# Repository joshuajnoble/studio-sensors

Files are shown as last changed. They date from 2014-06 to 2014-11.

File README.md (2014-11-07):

===============================================
frog studio sensor
===============================================

Let's keep it simple at first: there's a server and you can pull info from it. Here's what some of that info looks like:

```
[{"id":134,"sensor_id":1,"time":"2014-03-24T23:48:55.442Z","light":1,"sound":114,"movement":1,"temp":18,"humidity":147,"brightness":0},
{"id":135,"sensor_id":1,"time":"2014-03-24T23:49:20.120Z","light":1347,"sound":562,"movement":0,"temp":34,"humidity":3,"brightness":0}]
```

Whoa. That's JSON!

The frog studio sensors log all their data up there to my server every 15 seconds. 

Ok, so we have a few things in there:

* sensor_id: what sensor is it?
* studio: what studio is it in?
* zone: what part of the studio is it in?
* time: that's a timestamp (this is in GMT)
* sound: scale from 0-30 (afaict)
* movement: has anything moved in that zone in the last 30 seconds?
* humidity: what's the relative humidity (percent)
* temperature: Celsius
* light: light frequency in values from 480-600 (afaict)
* brightness: not being used right now

The raspberry pi just logs its data using a URL like:

`http://OUR_URL:3000/?i=1&l=343&s=232&t=22&h=33&m=0&&studio=sea&zone=1`

You can make fake (test) posts all you want.

===============================================
VISUALIZATION
===============================================

Where's the visualization? Good question. Have you made one yet? No? Well there's your answer. This is meant to look different to each studio. There are a few basic pattern goes like so:

`/view?params`

Let's look at some more stuff in here. You're *probably* going to want to just use the following:

`URL:3000/view?studio=SEA&begindate=24032014&begintime=1600&enddate=24032014&endtime=1700`

That gives you all the data from Seattle from 24032014:1600 to 24032014:1700 thats DDMMYY:24HR

There is more though, be warned though, these datasets can get massive and pulling them all is *slow*

All studios by date:

`URL:3000/view?begindate=24032014&begintime=1600&enddate=24032014&endtime=1700`

The last reading by zone

`URL:3000/view?studio=SEA&zone=1&last=1`

All readings by zone

`URL:3000/view?studio=SEA&zone=1`

All readings by sensorid (good for debugging)

`URL:3000/view?id=1`

Timeboxed view of a particular zone:

`URL:3000/?i=1&l=343&s=232&t=22&h=33&m=0&&studio=sea&zone=1`

All readings from the last hour

`URL:3000/view?recent=1&zone=1&studio=SEA`

The last reading of a studio

`URL:3000/view?now=1&studio=SEA`

Want more? It's very easy to add. Just take a look at studio-sensors/server.js for tips on how to make it better.

===============================================
DEVICE INFO
===============================================

The device is a Raspberry pi with some sensors on it. The first thing the device does is start up, report its IP, studio (within frog), location (zone), and then get a sensor id that will follow it as long as it (it, in this case being the SD card) exists.

This is accessed like so:

`$URL/get_id?studio=SEA&zone=1&ip=172.189.128.112`

When the machine is kicked off the network and hops back on that it updates its IP. This is done like so:

`$URL/update_id?id=1&ip=172.189.128.112`

The id you see there is the same ID that is retrieved when the machine is first started up. 

Why is this "id => IP" mapping important? Well, so that you can always SSH into your device and see what's up with it, if it crashed, if the DHT22 burnt out, etc. That's what makes it worthwhile to have everything on the RPI.

To configure the device to run the studio sensor program you need to do a few different things first.

1) Install the drivers for the Edimax EW-7811Un USB WiFi chip

http://www.andreagrandi.it/2014/09/02/how-to-configure-edimax-ew-7811un-wifi-dongle-on-raspbian/

2) Install pigpio

http://abyz.co.uk/rpi/pigpio/

3) Install git

sudo apt-get install git

4) Install Adafruit DHT22 driver

https://github.com/adafruit/Adafruit_Python_DHT

===============================================
SERVER INFO
===============================================

I have my server set up to use upstart to start up our node application, it's logging to :"/etc/init/studioapi.conf" at the moment so you can see what's going on with it.

I'm using ec2 ubuntu.

To get things set up I just did the following:

`sudo apt-get install postgres node`

then 

`sudo vim /etc/postgresql/9.3/main/postgresql.conf`

uncomment the line that says: `#listen_addresses = 'localhost' `
then
`sudo vim /etc/postgresql/9.3/main/pg_hba.conf`

then

`sudo service postgresql start`

then

```
sudo -i -u postgres
ubuntu@ip-172-31-30-171:~$ sudo -i -u postgres
postgres@ip-172-31-30-171:~$ psql
psql (9.3.5)
Type "help" for help.

ALTER USER postgres WITH PASSWORD '$password';
```

Create a job:

`sudo vim /etc/init/studioapi.conf`

then add:

```
description "node.js server"
author     "josh"

# used to be: start on startup
# until we found some mounts weren't ready yet while booting:
start on started mountall
stop on shutdown

# Automatically Respawn:
respawn
respawn limit 99 5

script
    # Not sure why $HOME is needed, but we found that it is:
    export HOME="/root"

    exec /usr/bin/node /home/joshuajnoble/studio-sensors/server.js >> /var/log/node.log 2>&1
end script

post-start script
   # Optionally put a script here that will notifiy you node has (re)started
   # /root/bin/hoptoad.sh "node.js has started!"
end script
```

===============================================
DB INFO
===============================================

Creating the DB is pretty simple:
```
create database sensordata;

create table sensors ( studio varchar(3), zone varchar(10), id integer, constraint uid unique(id), ip varchar(16) );

ALTER TABLE sensors ADD COLUMN key varchar(30);

ALTER TABLE sensors ADD CONSTRAINT uniquekey UNIQUE (key);

create table readings ( id serial, sensor id int not null, time timestamp with time zone not null, light int not null, sound int not null, movement int not null, temp int not null, humidity int not null, brightness int not null, zone varchar(30) not null, studio varchar(30) not null);
```

===============================================
Troubleshooting
===============================================

Can't get the Pi online?

Try making a little entry in crontab to make the RaspberryPi ping your router every minute. This will ensure that your wifi connection will stay alive. To edit crontab just type (from pi user, you don’t need to be root):

`crontab -e`

and insert this line at the end:

`*/1 * * * * ping -c 1 192.168.0.1`

where 192.168.0.1 is the IP of your router. I don't know what your studios router address will be, so you'll have to figure that out.

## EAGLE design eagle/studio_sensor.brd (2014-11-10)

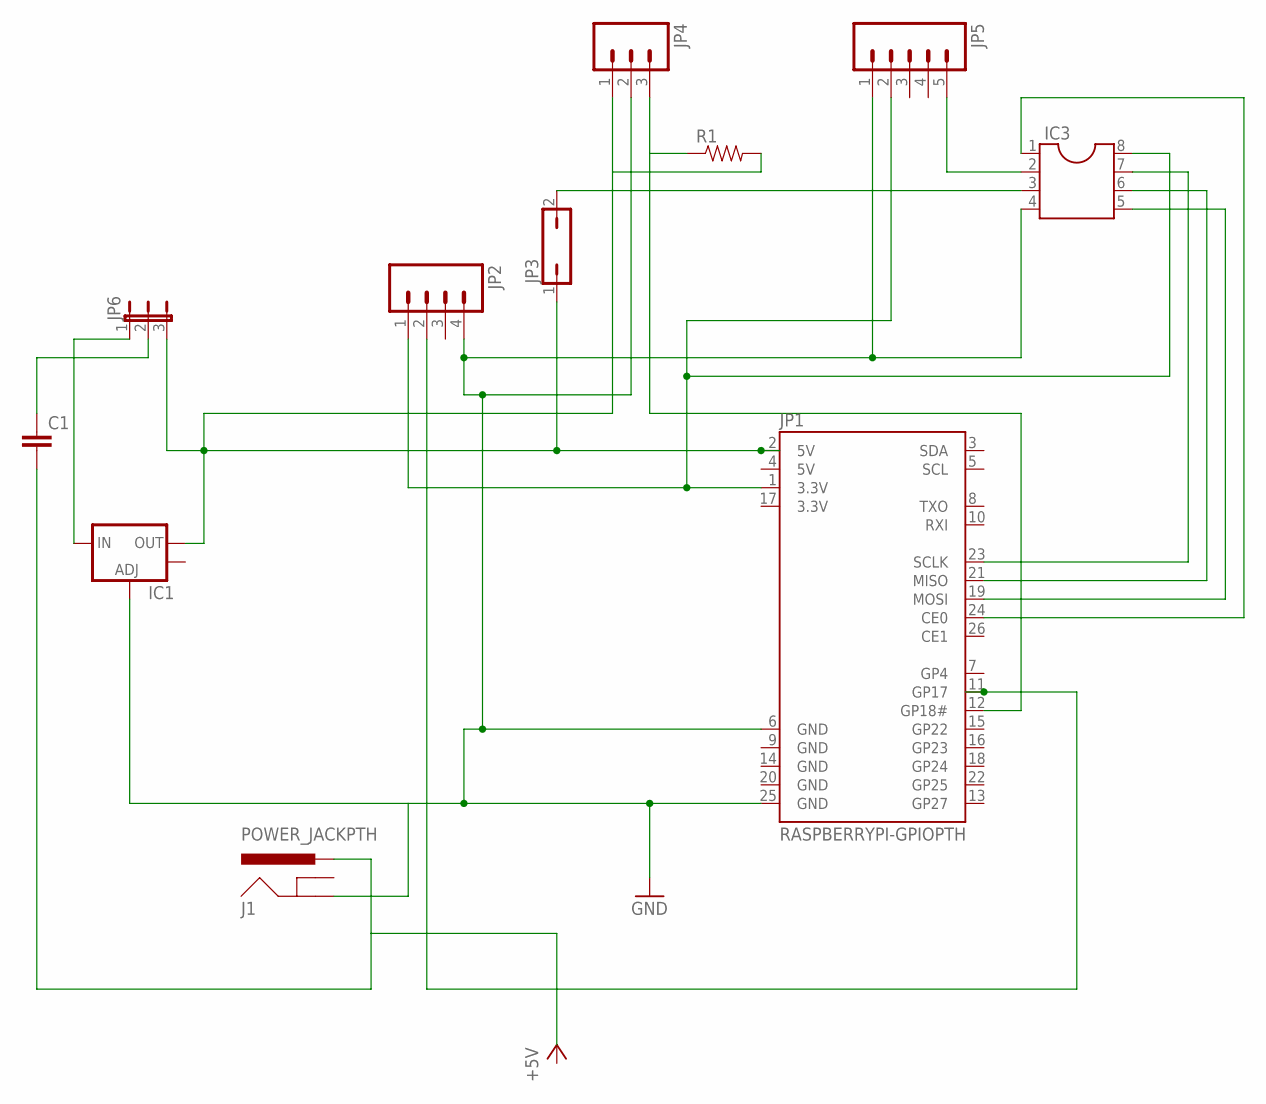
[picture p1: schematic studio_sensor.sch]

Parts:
C1: CAP0603-CAP; 0603-CAP
IC1: V_REG_LM1117SOT223; SOT223
IC3: DIL8S; SOCKET-08
J1: POWER_JACKPTH; POWER_JACK_PTH
JP1: RASPBERRYPI-GPIOPTH; 2X13-SHROUDED
JP2: M04PTH; 1X04
JP3: JP1Q; JP1
JP4: M03PTH; 1X03
JP5: M05PTH; 1X05
JP6: JP2E; JP2
R1: 4.7OHM1/10W5%(0603); 0603

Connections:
3.3V: JP1.17 (3.3V)
5V: JP1.4 (5V)
GND: IC1.1 (ADJ), IC3.4, J1.GND, JP1.6 (GND), JP1.9 (GND), JP1.14 (GND), JP1.20 (GND), JP1.25 (GND), JP2.4, JP4.2, JP5.1
unnamed: IC1.2 (OUT), JP1.2 (5V), JP3.1, JP4.1, JP6.3, R1.2
unnamed: IC3.8, JP1.1 (3.3V), JP2.1, JP5.2
unnamed: IC3.3, JP3.2
unnamed: IC3.7, JP1.23 (SCLK)
unnamed: IC3.6, JP1.21 (MISO)
unnamed: IC3.5, JP1.19 (MOSI)
unnamed: IC3.1, JP1.24 (CE0)
unnamed: IC3.2, JP5.5
unnamed: IC1.3 (IN), JP6.1
unnamed: JP1.11 (GP17), JP2.2
unnamed: C1.2, J1.PWR
unnamed: C1.1, JP6.2
unnamed: JP1.12 (GP18#), JP4.3, R1.1

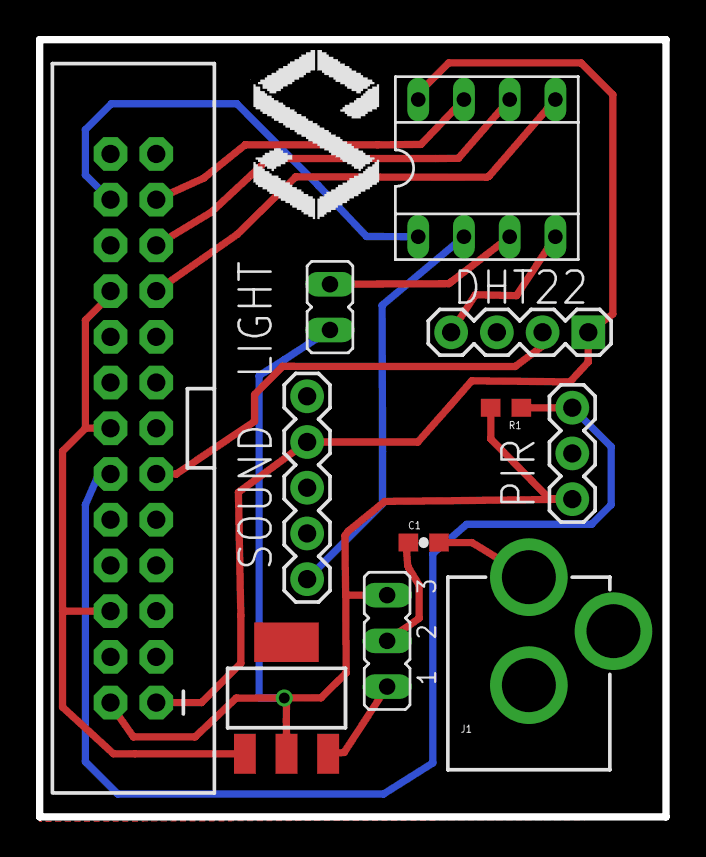
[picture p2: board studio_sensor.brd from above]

Board: 2 copper layers, 34.8 x 43.2 mm, 11 parts (0 on the bottom side), 14 nets.

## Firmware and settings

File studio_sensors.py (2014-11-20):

from __future__ import division
import struct
import socket
import fcntl
import getopt
import spidev
import time
import sys
from time import sleep
import pigpio
import urllib2
import httplib
import Adafruit_DHT
import datetime
import os
import contextlib
import subprocess
from subprocess import call

zone = ""
studio = ""

TSL235_pin = 7
DHT22_pin = 17
sensor_id = -1

IP = "54.191.189.58"
PORT = "3000"

def bitstring(n):
    s = bin(n)[2:]
    return '0'*(8-len(s)) + s

def readADC(adc_channel=0, spi_channel=0):
	conn = spidev.SpiDev(0, spi_channel)
	conn.max_speed_hz = 500000 # 1.2 MHz
	conn.mode = 0
	cmd = 192
	if adc_channel != 0:
		cmd += 32
	reply_bytes = conn.xfer2([cmd, 0])
	reply_bitstring = ''.join(bitstring(n) for n in reply_bytes)
	reply = reply_bitstring[5:15]
	conn.close()
	return int(reply, 2)

def get_ip_address(ifname):
	s = socket.socket(socket.AF_INET, socket.SOCK_DGRAM)
	return socket.inet_ntoa( fcntl.ioctl( s.fileno(), 0x8915, struct.pack('256s', ifname[:15]) )[20:24] )

def downUp():
	subprocess.Popen(["ifdown", "wlan0"],close_fds=True)
	sleep(10)
	subprocess.Popen(["ifup", "wlan0"],close_fds=True)
	sleep(20)


def rebootWlan0():
	downUp()
	hasIP = False
	while(hasIP == False):
		try:
			ip = get_ip_address("wlan0")
			hasIP = True
		except IOError:
			downUp()


	request = urllib2.Request('http://'+IP+':'+PORT+'/update_ip?id='+sensor_id+'&ip=' + ip)
	# recursively calls itself, could be bad
	try:
		response = urllib2.urlopen(request)
	except urllib2.HTTPError, e:
		#response.close()
		print(str(datetime.datetime.now()) + 'HTTPError = ' + str(e.code) )
		rebootWlan0()
	except urllib2.URLError, e:
		#response.close()
		rebootWlan0()
		print(str(datetime.datetime.now()) + 'URLError = ' + str(e.reason))
	except Exception:
		#response.close()
		import traceback
		print(str(datetime.datetime.now()) + 'generic exception: ' + traceback.format_exc())
		rebootWlan0()
		print(str(datetime.datetime.now()) +  " http error " )


def getHwAddr(ifname):
	s = socket.socket(socket.AF_INET, socket.SOCK_DGRAM)
	info = fcntl.ioctl(s.fileno(), 0x8927,  struct.pack('256s', ifname[:15]))
	return ''.join(['%02x' % ord(char) for char in info[18:24]])



# now begin the actual loop
####################################################################################################

if __name__ == "__main__":

	# Read command line args
	#myopts, args = getopt.getopt(sys.argv[1:],"s:z:")
 
	###############################
	# o == option
	# a == argument passed to the o
	###############################
	#for o, a in myopts:
	#	if o == '-s':
	#		studio=a
	#	elif o == '-z':
	#		zone=a
	#	else:
	#		print(str(datetime.datetime.now()) + "Usage: %s -s studio -z zone" % sys.argv[0])


	# FIRST
	# do we know our zone and studio?
	
	print( str(datetime.datetime.now()) + "start ") 
	has_studio_zone = False

	if os.path.isfile('studio_sensor_studio_zone') == False:
		print(str(datetime.datetime.now()) + " no studio + zone, getting one from server ")
		mac = getHwAddr("wlan0")
		print(str(datetime.datetime.now()) + " my mac is " + str(mac))
		while has_studio_zone == False:
			print(str(datetime.datetime.now()) +  " going to mac request from " + IP + ":" + PORT)
			request = urllib2.Request("http://"+str(IP)+":"+str(PORT)+"/get_studio_zone?mac="+str(mac))
			try:
				response = urllib2.urlopen(request)
				studio_zone = response.read()
				print(str(datetime.datetime.now()) + " got studio + zone " + str(studio_zone).split(':')[0] + " " + str(studio_zone).split(':')[1])
				f = open('studio_sensor_studio_zone', 'w')
				f.write(str(studio_zone))
				f.close()
				response.close()
				has_studio_zone = True
			except IndexError, e:
				print( str(datetime.datetime.now()) + " service didn't find this MAC address, add for this device and restart ")
				sys.exit()
			except urllib2.HTTPError, e:
				if(e.code == 409):
					print(str(datetime.datetime.now()) + ' DB error configure MAC ' + str(e.code))
					sys.exit()

 
				print(str(datetime.datetime.now()) + 'HTTPError = ' + str(e.code))
				#print(str(datetime.datetime.now()) + 'HTTPError = ' + str(e.code))
				downUp()
			except urllib2.URLError, e:
				downUp()
				print(str(datetime.datetime.now()) + 'URLError = ' + str(e.reason))
			except httplib.HTTPException, e:
				if(e.code == 409):
					print(str(datetime.datetime.now()) + ' DB error configure MAC ' + str(e.code))
					sys.exit()
				downUp()
				print(str(datetime.datetime.now()) + 'HTTPException')
			except Exception:
				import traceback
				print(str(datetime.datetime.now()) + 'generic exception: ' + traceback.format_exc())
			sleep(10)

	# we know our zone and studio, lets load it in

	if os.path.isfile('studio_sensor_studio_zone') == True:
		f = open('studio_sensor_studio_zone', 'r')
		studio_zone = f.read()
		studio = str(studio_zone).split(":")[0]
		zone = str(studio_zone).split(":")[1]
		f.close()    

	print (studio + " " + zone)

	pir_pin = 18
	pi = pigpio.pi()
	pi.set_mode(pir_pin, pigpio.INPUT)         # activate input

	sensor = Adafruit_DHT.DHT22

	pir_triggered = False
	has_id = False

	# if you have an ID file then you don't need to do this

	if os.path.isfile('studio_sensor_id') == False:
		print(str(datetime.datetime.now()) + " no ID, getting one from server ")
		ip = get_ip_address("wlan0")
		print(str(datetime.datetime.now()) + " my IP is " + str(ip))
		while has_id == False:
			print(str(datetime.datetime.now()) +  " going to request from " + IP + ":" + PORT)
			request = urllib2.Request("http://"+str(IP)+":"+str(PORT)+"/get_id?studio="+str(studio)+"&zone="+str(zone)+"&ip="+str(ip))
			#request = urllib2.Request("http://54.191.189.58:3000/get_id?studio=SEA&zone=1&ip=127.0.0.1")

			try:
				response = urllib2.urlopen(request)
				sensor_id = response.read()
				print(str(datetime.datetime.now()) + " got ID " + str(sensor_id))
				f = open('studio_sensor_id', 'w')
				f.write(str(sensor_id))
				f.close()
				response.close()
				has_id = True
			except urllib2.HTTPError, e:
				 print(str(datetime.datetime.now()) + 'HTTPError = ' + str(e.code))
				 downUp();
			except urllib2.URLError, e:
				 downUp();
				 print(str(datetime.datetime.now()) + 'URLError = ' + str(e.reason))
			except httplib.HTTPException, e:
				 downUp();
				 print(str(datetime.datetime.now()) + 'HTTPException')
			except Exception:
				 import traceback
				 print(str(datetime.datetime.now()) + 'generic exception: ' + traceback.format_exc())
				
			sleep(10)

	if os.path.isfile('studio_sensor_id') == True:
		f = open('studio_sensor_id', 'r')
		sensor_id = f.read()        
		f.close()    

	sound_values = [0] * 150
	sound_index = 0
	last_send = time.time()
	last_sound_sample = last_send

	while 1:
		sleep(0.05)
		if pi.read(pir_pin) == False:
			pir_triggered = True
		else:
			pir_triggered = False

		if( time.time() - last_sound_sample) > 5:
			sound_values[sound_index] = readADC()
			sound_index += 1
			last_sound_sample = time.time()

		# every 5 minutes?
		if (time.time() - last_send) > 300:
			print(str(datetime.datetime.now()) +  " sending ")
			send = "i=" + str(sensor_id) + "&studio="+ studio+ "&zone="+ zone
			if pir_triggered:
				send += "&m=1"
			else:
				send += "&m=0"
			light_value = readADC(1) #light is now just on MCP3002, tsl235 can stuff it
			send += "&l=" + str(light_value)
			
			sound_sum = 0
			for val in range(sound_index):
				sound_sum += abs( 512 - sound_values[val] )

			send += "&s=" + str(sound_sum / sound_index)
			# all done with sounds until next send
			sound_index = 0
			humidity, temperature = Adafruit_DHT.read_retry(sensor, DHT22_pin)
			print(str(datetime.datetime.now()) +  str(temperature) + " " + str(humidity))
			if temperature != None:
				send += "&t=" + str(int(temperature))
			else:
				send += "&t=0"

			if humidity != None:
				send += "&h=" + str(int(humidity))
			else:
				send += "&h=0"

			print(str(datetime.datetime.now()) +  send )

			# we're going to want this to allow us to pull this out of the
			# config file so it can be set from the desktop I'd think
			request = urllib2.Request('http://'+IP+':'+PORT+'/?'+send)
			try: 
				response = urllib2.urlopen(request)
				response.close()
			except urllib2.HTTPError, e:
				#response.close()
				print(str(datetime.datetime.now()) + " HTTP ERROR = " + str(e.code))
				if( e.code == 409 ):
					print(str(datetime.datetime.now()) + " We're getting a 409 which means a misconfigured request and resulting DB error ")
				else:
					rebootWlan0()
			except urllib2.URLError, e:
				#response.close()
				rebootWlan0()
				print(str(datetime.datetime.now()) + 'URLError = ' + str(e.reason))
			except Exception:
				#response.close()
				import traceback
				print(str(datetime.datetime.now()) + 'generic exception: ' + traceback.format_exc())
				rebootWlan0()
				print(str(datetime.datetime.now()) +  " http error " )

			last_send = time.time()
# end

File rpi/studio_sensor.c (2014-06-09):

#include <stdio.h>
#include <stdlib.h>
#include <unistd.h>
#include <errno.h>
#include <string.h>
#include <netdb.h>
#include <sys/types.h>
#include <netinet/in.h>
#include <sys/socket.h>

#include <arpa/inet.h>

#define PORT "3000" // the port client will be connecting to 

#define MAXDATASIZE 100 // max number of bytes we can get at once 
spiDevice *spiDevice;

struct atmosphereData {
  char temp[2];
  char humidity[2];
}

// get sockaddr, IPv4 or IPv6:
void *get_in_addr(struct sockaddr *sa)
{
    if (sa->sa_family == AF_INET) {
        return &(((struct sockaddr_in*)sa)->sin_addr);
    }

    return &(((struct sockaddr_in6*)sa)->sin6_addr);
}

int connectAndSend(int argc, char *argv[])
{
    int sockfd, numbytes;  
    char buf[MAXDATASIZE];
    struct addrinfo hints, *servinfo, *p;
    int rv;
    char s[INET6_ADDRSTRLEN];

    memset(&hints, 0, sizeof hints);
    hints.ai_family = AF_UNSPEC;
    hints.ai_socktype = SOCK_STREAM;

    if ((rv = getaddrinfo(hostname, PORT, &hints, &servinfo)) != 0) {
        fprintf(stderr, "getaddrinfo: %s\n", gai_strerror(rv));
        return 1;
    }

    // loop through all the results and connect to the first we can
    for(p = servinfo; p != NULL; p = p->ai_next) {
        if ((sockfd = socket(p->ai_family, p->ai_socktype, p->ai_protocol)) == -1) {
            perror("client: socket");
            continue;
        }

        if (connect(sockfd, p->ai_addr, p->ai_addrlen) == -1) {
            close(sockfd);
            perror("client: connect");
            continue;
        }

        break;
    }

    if (p == NULL) {
        fprintf(stderr, "client: failed to connect\n");
        return 2;
    }

    inet_ntop(p->ai_family, get_in_addr((struct sockaddr *)p->ai_addr), s, sizeof s);
    printf("client: connecting to %s\n", s);

    freeaddrinfo(servinfo); // all done with this structure

    if ((numbytes = recv(sockfd, buf, MAXDATASIZE-1, 0)) == -1) {
        perror("recv");
        exit(1);
    }

    buf[numbytes] = '\0';

    printf("client: received '%s'\n",buf);

    close(sockfd);
}

int readVolume( int pin )
{
  spiWriteRead( )
}


int readDHT(int pin, atmosphereData* aData) {
  int counter = 0;
  int laststate = HIGH;
  int j=0;

  // Set GPIO pin to output
  bcm2835_gpio_fsel(pin, BCM2835_GPIO_FSEL_OUTP);

  bcm2835_gpio_write(pin, HIGH);
  usleep(500000);  // 500 ms
  bcm2835_gpio_write(pin, LOW);
  usleep(20000);

  bcm2835_gpio_fsel(pin, BCM2835_GPIO_FSEL_INPT);

  data[0] = data[1] = data[2] = data[3] = data[4] = 0;

  // wait for pin to drop?
  while (bcm2835_gpio_lev(pin) == 1) {
    usleep(1);
  }

  // read data!
  for (int i=0; i< MAXTIMINGS; i++) {
    counter = 0;
    while ( bcm2835_gpio_lev(pin) == laststate) {
      	counter++;
      	//nanosleep(1);		// overclocking might change this?
        if (counter == 1000) {
	         break;
         }
    }
    laststate = bcm2835_gpio_lev(pin);
    if (counter == 1000) break;
    bits[bitidx++] = counter;

    if ((i>3) && (i%2 == 0)) {
      // shove each bit into the storage bytes
      data[j/8] <<= 1;
      if (counter > 200)
        data[j/8] |= 1;
      j++;
    }
  }


#ifdef DEBUG
  for (int i=3; i<bitidx; i+=2) {
    printf("bit %d: %d\n", i-3, bits[i]);
    printf("bit %d: %d (%d)\n", i-2, bits[i+1], bits[i+1] > 200);
  }
#endif

  printf("Data (%d): 0x%x 0x%x 0x%x 0x%x 0x%x\n", j, data[0], data[1], data[2], data[3], data[4]);

  if ((j >= 39) && (data[4] == ((data[0] + data[1] + data[2] + data[3]) & 0xFF)) ) 
  {
     // yay!
 
  	float f, h;
  	h = data[0] * 256 + data[1];
  	h /= 10;

  	f = (data[2] & 0x7F)* 256 + data[3];
    f /= 10.0;
    if (data[2] & 0x80)  f *= -1;
    //printf("Temp =  %.1f *C, Hum = %.1f \%\n", f, h);
    itoa(f, aData->temp);
    itoa(h, aData->humidity);
    return 1;
  }

  return 0;
}

void main()
{
  spiDevice = malloc(sizeof(spiDevice));
  spiDevice->mode = SPI_MODE_0;
  spiDevice->bitsPerWord = 8;
  spiDevice->speed = 1000000;
  spiDevice->spifd = -1;

  char adc08636 = "/dev/spidev0.0";

  if(spiOpen(spiDevice, adc08636, sizeof(adc08636)) < 0) {
    perror(" can't open spidev0.0");
  }

  atmosphereData dhtData;
  unsigned char dataDump[255];
  unsigned char spiData[2];
  int soundValue;

  while()
  {

    /*

      keep track of time,
      check sound, check movement
      if it's been long enough, throw it up to the sensor

     */

    readDHT( dhtPin, &dhtData );
    spiWriteRead( &spiDevice, )
    // we dont really care what we're sending b/c we're only reading
    soundValue = connectAndSend( &spiData[0], 2 );
    

  }


}

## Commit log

2014-03-15 adding arduino files
2014-03-18 adding proper URL, adjusting interrupt
    [soldering.fzz]
2014-03-25 updating server and arduino
2014-03-26 cleaning up arduino app
2014-04-17 re-adding studio sensors
2014-05-01 updating server, last ditch try w/the watchdog timer
2014-06-13 updating dht sensor reading
2014-07-23 adding studio sensors py
2014-08-08 adding schematics
    [studio_sensor.brd, studio_sensor.sch]
2014-09-12 updating studio sensors
    [studio_sensor.brd, studio_sensor.sch]
2014-10-14 updates for correct pins
    [studio_sensors.py]
2014-10-16 sensor readings every 10min
2014-10-20 no more leaking FDs
    [studio_sensors.py]
2014-10-20 redoing DB
    [studio_sensor.brd, studio_sensor.sch]
2014-10-20 fixing on the fly
    [server.js]
2014-10-20 updating sensor
2014-10-21 server insert fixes
2014-10-21 updating studio sensor
2014-11-04 sensor key must be unique
2014-11-06 server updates
    [studio_sensor.brd, studio_sensor.sch]
2014-11-07 adding more error handling for bad networks
    [studio_sensors.py]
2014-11-07 massive cleanup
    [soldering.fzz]
2014-11-11 cleaningup studio sensors
2014-11-12 adding time stamps to error messages
    [studio_sensors.py]
2014-11-17 error handling for no MAC
    [studio_sensors.py]
2014-11-21 case mismatch on MAC

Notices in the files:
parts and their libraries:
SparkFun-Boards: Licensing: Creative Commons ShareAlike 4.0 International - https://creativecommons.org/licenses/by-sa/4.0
